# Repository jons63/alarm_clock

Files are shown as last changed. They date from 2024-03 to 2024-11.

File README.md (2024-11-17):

# Alarm clock with mp3 song support
This project spawned when my sister was looking to switch out her phone for an alarm clock.
She said that she easily wakes up in the morning so the normal alarm sounds are to harsh and
she would instead like to have nature sound like the ones usually available in wake up light
alarm clocks. I did a modest effort in trying to find what she wanted but when I finally
found an alarm clock that had nature sounds and no light the sound was horrible.
And now im here after thinking "how hard can it be to make an alarm clock that sounds decent?".

## The display
Any seven segment display with four digits should work for an alarm clock. I went with the largest available one.

Below is the wiring for the display + one button for incrementing the value shown.

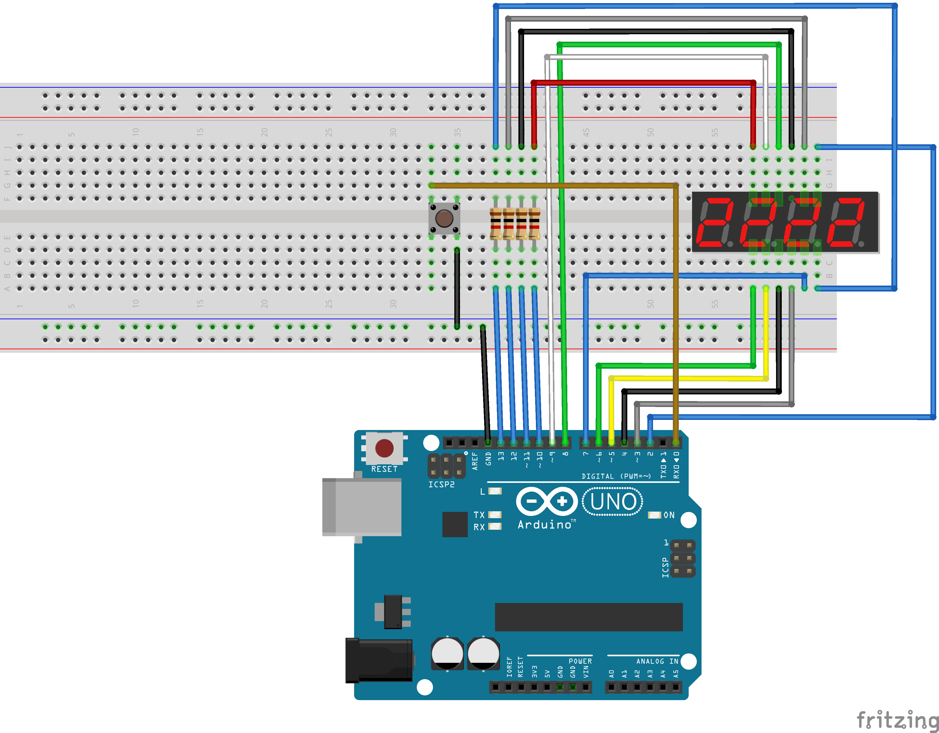
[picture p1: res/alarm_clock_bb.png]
display


## Display with shift register
A seven segment display require a lot of pins to operate, twelve for a display with four digits. To get around this I use a shift register to only use seven pins on the arduino instead of twelve.
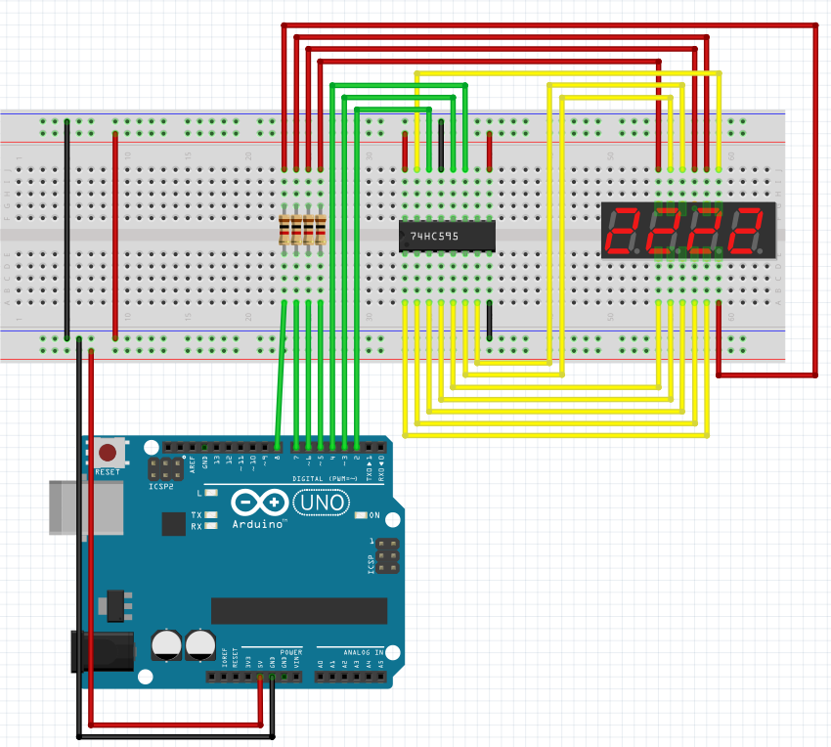
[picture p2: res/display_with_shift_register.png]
display with shift register

But even when using a shift register the amount of digital pins on one Arduino Uno is not enough when adding the MP3 player and buttons. Also, when adding logic to handle button presses and the alarm functionality the update frequence of the display gets low enough for it to be visibly flickering. To combat this I will add another Arduino Uno that will only refresh the display and the second arduino will handle the logic. They will use i2c communication to change what time should be displayed and other functoin that might be needed.

## Dual Arduino Uno with i2c communication. 
i2c is an easy communication interface with good Arduino support from the Wire library. I copied a simple example of i2c communication between two Arduinos to test it out.
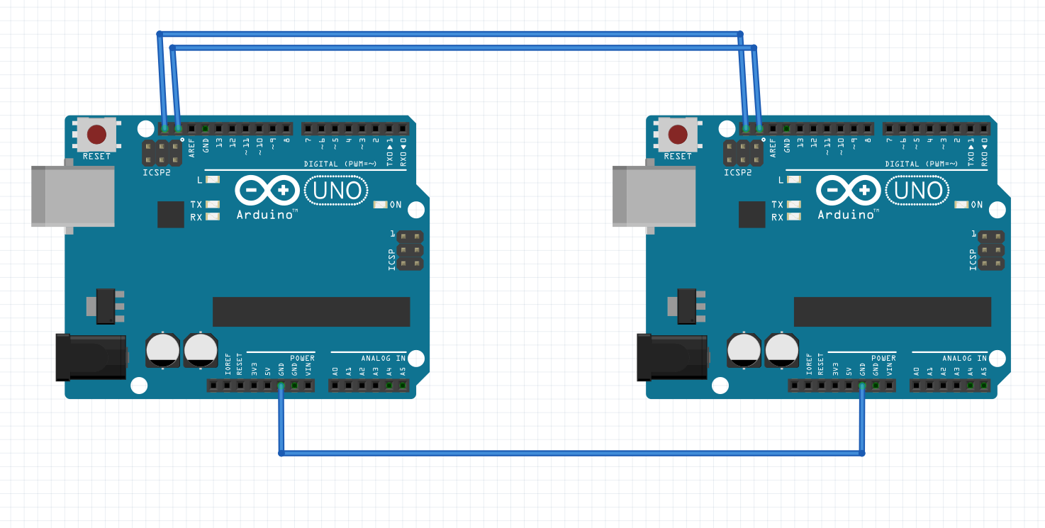
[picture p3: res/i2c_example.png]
Minimal Arduino i2c example


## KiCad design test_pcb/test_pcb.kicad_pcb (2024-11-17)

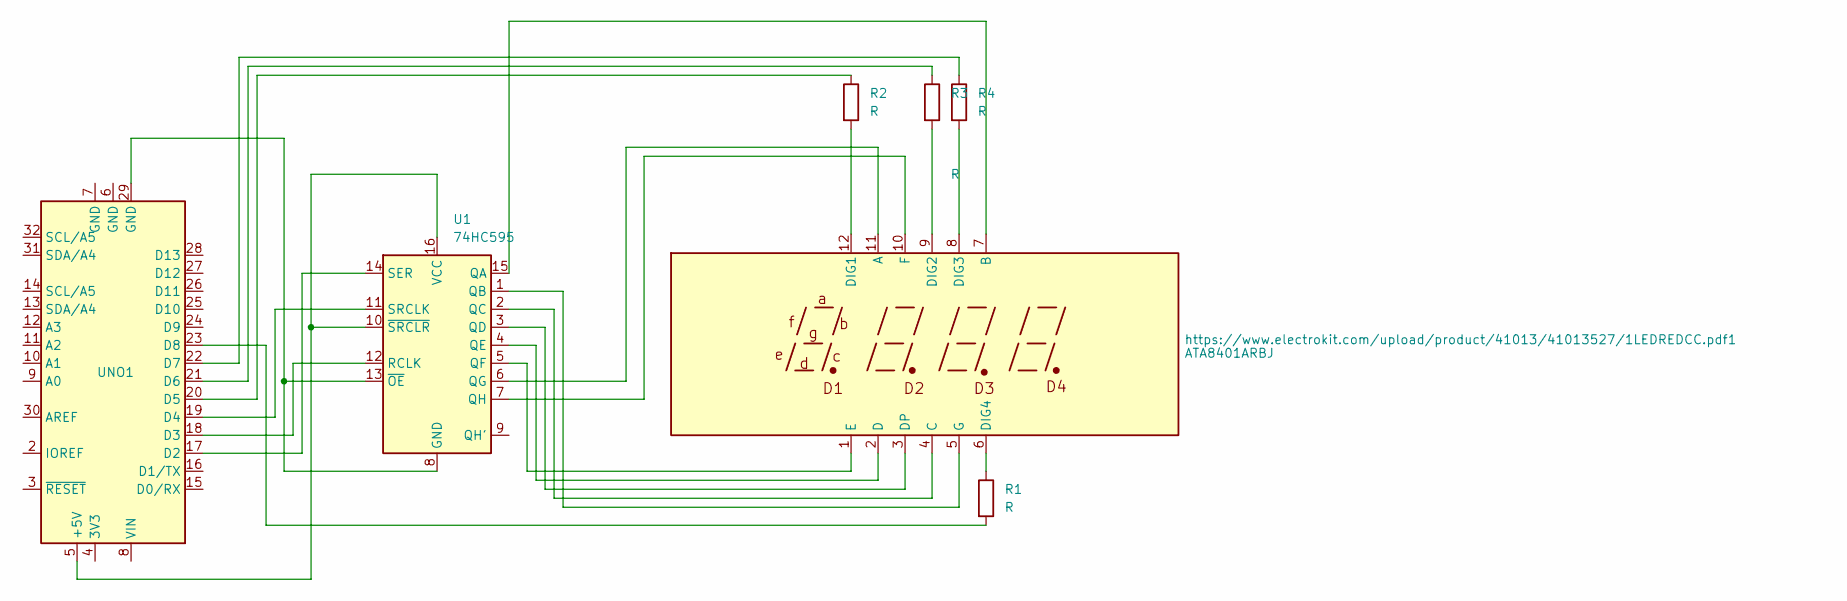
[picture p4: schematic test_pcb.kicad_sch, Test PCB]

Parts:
R1, R2, R3, R4: R; R_Axial_DIN0207_L6.3mm_D2.5mm_P10.16mm_Horizontal
U1: 74HC595; DIP-16_W7.62mm_Socket
UNO1: Arduino UNO R3 Outline
https://www.electrokit.com/upload/product/41013/41013527/1LEDREDCC.pdf1: ATA8401ARBJ

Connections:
unnamed: U1.8 (GND), U1.13 (~OE), UNO1.29 (GND)
unnamed: U1.15 (QA), https://www.electrokit.com/upload/produ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.7 (B)
unnamed: U1.1 (QB), https://www.electrokit.com/upload/produ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.5 (G)
unnamed: U1.2 (QC), https://www.electrokit.com/upload/produ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.4 (C)
unnamed: U1.3 (QD), https://www.electrokit.com/upload/produ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.3 (DP)
unnamed: U1.4 (QE), https://www.electrokit.com/upload/produ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.2 (D)
unnamed: U1.5 (QF), https://www.electrokit.com/upload/produ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.1 (E)
unnamed: U1.6 (QG), https://www.electrokit.com/upload/produ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.11 (A)
unnamed: U1.7 (QH), https://www.electrokit.com/upload/produ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.10 (F)
unnamed: U1.12 (RCLK), UNO1.18 (D3)
unnamed: U1.14 (SER), UNO1.17 (D2)
unnamed: U1.11 (SRCLK), UNO1.19 (D4)
unnamed: U1.10 (~SRCLR), U1.16 (VCC), UNO1.5 (+5V)
unnamed: R2.1, UNO1.20 (D5)
unnamed: R3.1, UNO1.21 (D6)
unnamed: R4.1, UNO1.22 (D7)
unnamed: R1.2, UNO1.23 (D8)
unnamed: R2.2, https://www.electrokit.com/upload/produ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.12 (DIG1)
unnamed: R3.2, https://www.electrokit.com/upload/produ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.9 (DIG2)
unnamed: R4.2, https://www.electrokit.com/upload/produ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.8 (DIG3)
unnamed: R1.1, https://www.electrokit.com/upload/produ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.6 (DIG4)

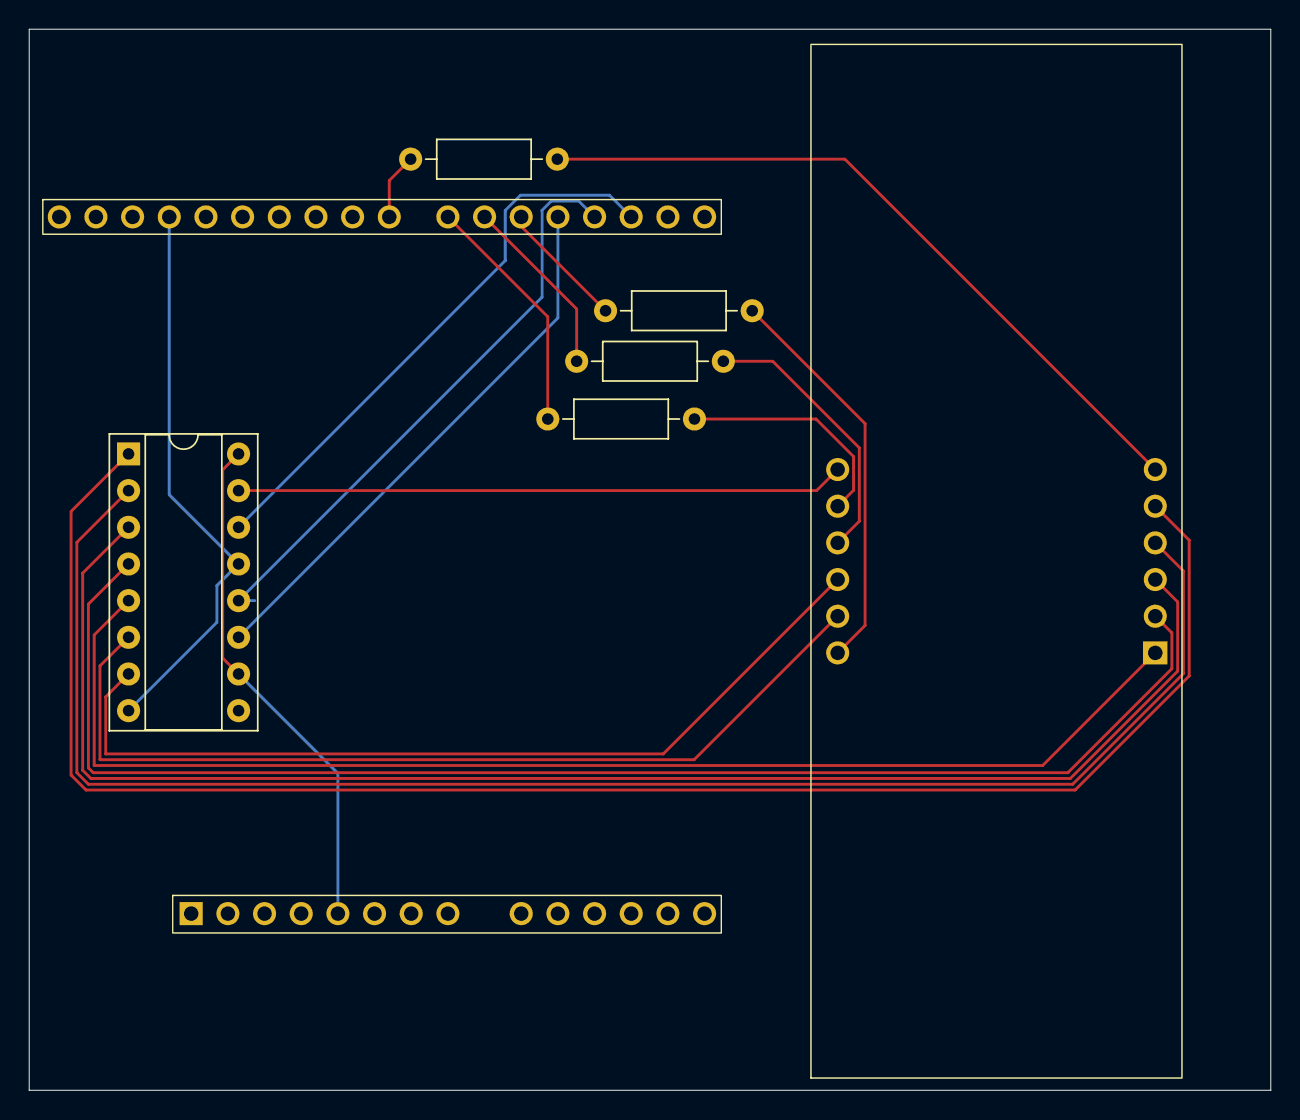
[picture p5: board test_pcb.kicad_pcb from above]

Board: 2 copper layers, 86.0 x 73.5 mm, 7 parts (0 on the bottom side), 21 nets.

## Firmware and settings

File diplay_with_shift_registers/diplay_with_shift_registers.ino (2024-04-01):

#include <DFRobotDFPlayerMini.h>
#include <TimeLib.h>
#include <SoftwareSerial.h>

#include "SevSegShift.h"

#define SHIFT_PIN_DS   2 /* Data input PIN */
#define SHIFT_PIN_STCP 3 /* Shift Register Storage PIN */
#define SHIFT_PIN_SHCP 4 /* Shift Register Shift PIN */

//Instantiate a seven segment controller object (with Shift Register functionality)
SevSegShift sevsegshift(
                  SHIFT_PIN_DS, 
                  SHIFT_PIN_SHCP, 
                  SHIFT_PIN_STCP, 
                  1, /* number of shift registers */
                  true /* Digits are connected to Arduino directly */
                );

SoftwareSerial softSerial(/*rx =*/10, /*tx =*/11);
#define FPSerial softSerial
DFRobotDFPlayerMini myDFPlayer;
void printDetail(uint8_t type, int value);

int val = 0;
unsigned long lastButtonPressTime = 0;
// Wait time in ms between two button presses
const int kTimeout = 100;

#define ADD 0
#define SETTINGS 1

enum class AddState : unsigned int {
  Idle = 0,
  Add_Ongoing = 1,
};

enum class Mode : unsigned int {
  Normal = 0,
  Settings = 1,
};

AddState state = AddState::Idle;
Mode mode = Mode::Normal;

class Button {
  public:
  Button(unsigned int pin) : pin_{pin} {};
  virtual void normal_action();
  virtual void settings_action();
  void operator()()  {
    if (!time_) {
      int new_state = digitalRead(pin_);
      if (new_state != last_state_ && new_state == LOW) {
        last_state_ = new_state;
        action();
        time_ = millis();
      } else if (new_state != last_state_ && new_state == HIGH) {
        last_state_ = new_state;
      }
    } else if (millis() - time_ > kTimeout) {
      time_ = 0;
    }
  };

  void action() {
    if (mode == Mode::Normal) {
      normal_action();
    } else if (mode == Mode::Settings) {
      settings_action();
    }
  };

  private:
    unsigned long time_{0};
    int last_state_{HIGH};
    unsigned int pin_;
};

class ToggleButton : public Button {
  public:
  ToggleButton(unsigned int pin) : Button(pin) {};
  void normal_action() override {
    Serial.println("Normal");
    sevsegshift.setNumber(0, 2);
    mode = Mode::Settings;
  }

  void settings_action() override {
    Serial.println("Settings");
    mode = Mode::Normal;
  }
};

ToggleButton btn(1);



void setupLogic() {
  pinMode(ADD, INPUT_PULLUP);
  pinMode(SETTINGS, INPUT_PULLUP);
}

void setupDisplay() {
  setTime(0,0,0,0,0,0);
  byte numDigits = 4;
  byte digitPins[] = {5, 6, 7, 8};
  byte segmentPins[] = {6, 0, 2, 4, 5, 7, 1, 3};
  bool resistorsOnSegments = false;
  bool updateWithDelays = false;
  bool leadingZeros = true;
  byte hardwareConfig = COMMON_CATHODE;
  bool disableDecPoint = false;

  sevsegshift.begin(hardwareConfig, numDigits, digitPins, segmentPins, resistorsOnSegments, updateWithDelays, leadingZeros, disableDecPoint);
  sevsegshift.setBrightness(20);
}

void setupAudio() {
  FPSerial.begin(9600);

  Serial.println();
  Serial.println(F("DFRobot DFPlayer Mini Demo"));
  Serial.println(F("Initializing DFPlayer ... (May take 3~5 seconds)"));

  if (!myDFPlayer.begin(FPSerial, /*isACK = */true, /*doReset = */true)) {  //Use serial to communicate with mp3.
    Serial.println(F("Unable to begin:"));
    Serial.println(F("1.Please recheck the connection!"));
    Serial.println(F("2.Please insert the SD card!"));
    while(true){
      delay(0); // Code to compatible with ESP8266 watch dog.
    }
  }
  Serial.println(F("DFPlayer Mini online."));

  myDFPlayer.volume(10);  //Set volume value. From 0 to 30
  myDFPlayer.play(2);  //Play the first mp3
}

void setup(){
  Serial.begin(9600);
  Serial.println("This is the start of the program");

  setupDisplay();

  //setupAudio();
}

bool logic() {
  if(lastButtonPressTime) {
    if(millis() - lastButtonPressTime > kTimeout){
      lastButtonPressTime = 0;
    } else {
      return false;
    }
  }
  if (digitalRead(ADD) && state == AddState::Idle) {
    state = AddState::Add_Ongoing;
    lastButtonPressTime = millis();
    return true;
  } else if(!digitalRead(ADD) && state == AddState::Add_Ongoing) {
    state = AddState::Idle;
  } else {
    return false;
  }
}

void display() {
  time_t t = now();
  int m = minute(t);
  m = m * 100;
  int s = second(t);  

  sevsegshift.setNumber(m+s, 2);
  /*
  if (logic()) {
    val +=1;
    sevseg.setNumber(val, 2);
  }
  */
}

void audio() {
  static unsigned long timer = millis();

  if (millis() - timer > 3000) {
    timer = millis();
    //myDFPlayer.next();  //Play next mp3 every 3 second.
  }

  if (myDFPlayer.available()) {
    printDetail(myDFPlayer.readType(), myDFPlayer.read()); //Print the detail message from DFPlayer to handle different errors and states.
  }
}

void settings() {

}

void check_input(){
  btn();
}

void loop(){
  //check_input();
  //if (mode == Mode::Normal) {
  display();  
  //audio();
  //} else if (mode == Mode::Settings) {
    //settings();
  //}

  sevsegshift.refreshDisplay(); 
}

void printDetail(uint8_t type, int value){
  switch (type) {
    case TimeOut:
      Serial.println(F("Time Out!"));
      break;
    case WrongStack:
      Serial.println(F("Stack Wrong!"));
      break;
    case DFPlayerCardInserted:
      Serial.println(F("Card Inserted!"));
      break;
    case DFPlayerCardRemoved:
      Serial.println(F("Card Removed!"));
      break;
    case DFPlayerCardOnline:
      Serial.println(F("Card Online!"));
      break;
    case DFPlayerUSBInserted:
      Serial.println("USB Inserted!");
      break;
    case DFPlayerUSBRemoved:
      Serial.println("USB Removed!");
      break;
    case DFPlayerPlayFinished:
      Serial.print(F("Number:"));
      Serial.print(value);
      Serial.println(F(" Play Finished!"));
      break;
    case DFPlayerError:
      Serial.print(F("DFPlayerError:"));
      switch (value) {
        case Busy:
          Serial.println(F("Card not found"));
          break;
        case Sleeping:
          Serial.println(F("Sleeping"));
          break;
        case SerialWrongStack:
          Serial.println(F("Get Wrong Stack"));
          break;
        case CheckSumNotMatch:
          Serial.println(F("Check Sum Not Match"));
          break;
        case FileIndexOut:
          Serial.println(F("File Index Out of Bound"));
          break;
        case FileMismatch:
          Serial.println(F("Cannot Find File"));
          break;
        case Advertise:
          Serial.println(F("In Advertise"));
          break;
        default:
          break;
      }
      break;
    default:
      break;
  }
}

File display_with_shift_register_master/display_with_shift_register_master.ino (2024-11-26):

#include <TimeLib.h>
#include <Wire.h>
#include <SoftwareSerial.h>
#include <DFRobotDFPlayerMini.h>

// For DFPlayer
SoftwareSerial softSerial(/*rx =*/10, /*tx =*/11);
#define FPSerial softSerial
DFRobotDFPlayerMini myDFPlayer;
void printDetail(uint8_t type, int value);

unsigned long lastButtonPressTime = 0;
// Wait time in ms between two button presses
const int kTimeout = 500;

#define SETTINGS 2
#define ACTION   3
#define ALARM    4

enum class Mode : unsigned int {
  Normal = 0,
  TimeMinutes = 1,
  TimeHours = 2,
  AlarmMinutes = 3,
  AlarmHours = 4,
  Brightness = 5,
};

time_t time_{now()};

Mode mode_{Mode::Normal};
unsigned int brightness_{20};
struct Alarm {
  time_t alarm_time{0};
  bool alarm_active{false};
  time_t alarm_off;
};

Alarm alarm_;
void SendTime(time_t t);
void SendBrightness(byte brightness);

void setupAudio() {
  FPSerial.begin(9600);

  Serial.println();
  Serial.println(F("DFRobot DFPlayer Mini Demo"));
  Serial.println(F("Initializing DFPlayer ... (May take 3~5 seconds)"));

  if (!myDFPlayer.begin(FPSerial, /*isACK = */true, /*doReset = */true)) {  //Use serial to communicate with mp3.
    Serial.println(F("Unable to begin:"));
    Serial.println(F("1.Please recheck the connection!"));
    Serial.println(F("2.Please insert the SD card!"));
    while(true){
      delay(0); // Code to compatible with ESP8266 watch dog.
    }
  }
  Serial.println(F("DFPlayer Mini online."));

  myDFPlayer.volume(15);  //Set volume value. From 0 to 30
}

class Button {
  public:
  Button(unsigned int pin, void (*func)()) : pin_{pin}, func_{func} {};
  void operator()()  {
    if (!time_) {
      int new_state = digitalRead(pin_);
      if (new_state != last_state_ && new_state == LOW) {
        last_state_ = new_state;
        func_();
        time_ = millis();
      } else if (new_state != last_state_ && new_state == HIGH) {
        last_state_ = new_state;
      }
    } else if (millis() - time_ > kTimeout) {
      time_ = 0;
    }
  };

  private:
    unsigned long time_{0};
    int last_state_{HIGH};
    unsigned int pin_;
    void (*func_)();
};

void ActionFunction() {
  switch (mode_) {
    case Mode::TimeMinutes:
      time_ += 1;
      setTime(time_);
      SendTime(time_);
      break;
    case Mode::TimeHours:
      time_ += 60;
      setTime(time_);
      SendTime(time_);
      break;
    case Mode::AlarmMinutes:
      alarm_.alarm_time += 1;
      SendTime(alarm_.alarm_time);
      break;
    case Mode::AlarmHours:
      alarm_.alarm_time += 60;
      SendTime(alarm_.alarm_time);
      break;
    case Mode::Brightness:
      if (brightness_ >= 100) {
        brightness_ = 0;
      } else {
        brightness_ += 10;
      }
      SendBrightness(brightness_);
      break;
    default:
      break;
  }
}

void ModeFunction() {
  switch (mode_) {
    case Mode::Normal:
      SendTime(time_);
      mode_ = Mode::TimeMinutes;
      break;
    case Mode::TimeMinutes:
      SendTime(time_);
      mode_ = Mode::TimeHours;
      break;
    case Mode::TimeHours:
      SendTime(alarm_.alarm_time);
      mode_ = Mode::AlarmMinutes;
      break;
    case Mode::AlarmMinutes:
      SendTime(alarm_.alarm_time);
      mode_ = Mode::AlarmHours;
      break;
    case Mode::AlarmHours:
      SendTime(time_);
      mode_ = Mode::Brightness;
      break;
    case Mode::Brightness:
      mode_ = Mode::Normal;
      break;
  }
  if (mode_ == Mode::Normal) {
    
  } else if (mode_ == Mode::TimeMinutes) {
    
  } else if (mode_ == Mode::TimeHours) {
    
  }else if (mode_ == Mode::Brightness) {
    
  }
  Serial.print("ModeFunction, mode:");
  Serial.println((int)mode_);
}

Button btn(SETTINGS, &ModeFunction);
Button btn2(ACTION, &ActionFunction);

void setup(){
  Serial.begin(9600);
  Wire.begin();
  pinMode(SETTINGS, INPUT_PULLUP);
  pinMode(ACTION, INPUT_PULLUP); 
  pinMode(ALARM, INPUT_PULLUP); 
  setupAudio();
  Serial.println("This is the start of the program");
}

void CheckInput(){
  btn();
  btn2();
}

// time_t == unsinged long == 4 bytes == 32 bits
void SendTime(time_t t) {
  int s = second(t);
  int m = minute(t);
  m = m * 100;
  t = m+s;
  Wire.beginTransmission(8); 
  Wire.write(0);
  Wire.write(t>>24);
  Wire.write(t>>16);
  Wire.write(t>>8);
  Wire.write(t);
  Wire.endTransmission();  
}

void SendBrightness(byte brightness) {
  Wire.beginTransmission(8); 
  Wire.write(1);
  Wire.write(brightness);
  Wire.endTransmission();  
}

void loop(){
  time_t t = now();
  if ((mode_ == Mode::Normal) && (t - time_ > 0)) {
    SendTime(t);
    time_ = t;
  }

  if (alarm_.alarm_active && digitalRead(ALARM) == HIGH) {
    alarm_.alarm_active = false;
    myDFPlayer.pause();
    alarm_.alarm_off = now();
    Serial.println("Alarm is now inactive");
  }

  if (minute(time_) == minute(alarm_.alarm_time) &&
      minute(now()) > minute(alarm_.alarm_off)) {
    if (digitalRead(ALARM) == LOW && !alarm_.alarm_active) {
      alarm_.alarm_active = true;
      myDFPlayer.loop(2);
      Serial.println("Alarm is now active");
    } 
  } 

  if (alarm_.alarm_active && minute(now())-minute(alarm_.alarm_time) >= 1) {
      alarm_.alarm_active = false;
      myDFPlayer.pause();
      Serial.println("Alarm is now inactive");
  }

  CheckInput();
}

void printDetail(uint8_t type, int value){
  switch (type) {
    case TimeOut:
      Serial.println(F("Time Out!"));
      break;
    case WrongStack:
      Serial.println(F("Stack Wrong!"));
      break;
    case DFPlayerCardInserted:
      Serial.println(F("Card Inserted!"));
      break;
    case DFPlayerCardRemoved:
      Serial.println(F("Card Removed!"));
      break;
    case DFPlayerCardOnline:
      Serial.println(F("Card Online!"));
      break;
    case DFPlayerUSBInserted:
      Serial.println("USB Inserted!");
      break;
    case DFPlayerUSBRemoved:
      Serial.println("USB Removed!");
      break;
    case DFPlayerPlayFinished:
      Serial.print(F("Number:"));
      Serial.print(value);
      Serial.println(F(" Play Finished!"));
      break;
    case DFPlayerError:
      Serial.print(F("DFPlayerError:"));
      switch (value) {
        case Busy:
          Serial.println(F("Card not found"));
          break;
        case Sleeping:
          Serial.println(F("Sleeping"));
          break;
        case SerialWrongStack:
          Serial.println(F("Get Wrong Stack"));
          break;
        case CheckSumNotMatch:
          Serial.println(F("Check Sum Not Match"));
          break;
        case FileIndexOut:
          Serial.println(F("File Index Out of Bound"));
          break;
        case FileMismatch:
          Serial.println(F("Cannot Find File"));
          break;
        case Advertise:
          Serial.println(F("In Advertise"));
          break;
        default:
          break;
      }
      break;
    default:
      break;
  }
}

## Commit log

2024-04-01 Use shift register to reduce number of arduino pins used to drive the display.
    [alarm_clock.fzz]
2024-11-17 Add i2c example
    [alarm_clock.fzz, arduino_i2c_example.fzz, atmega328_standalone.fzz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]
2024-11-21 Adds example of reading/writing time beween 2 arduinos
